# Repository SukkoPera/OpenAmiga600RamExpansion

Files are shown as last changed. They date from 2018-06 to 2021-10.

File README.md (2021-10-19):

# OpenAmiga600RamExpansion
OpenAmiga600RamExpansion is an Open Hardware 1 MB Chip RAM Expansion for the Commodore Amiga 600 Computer with optional Real Time Clock.

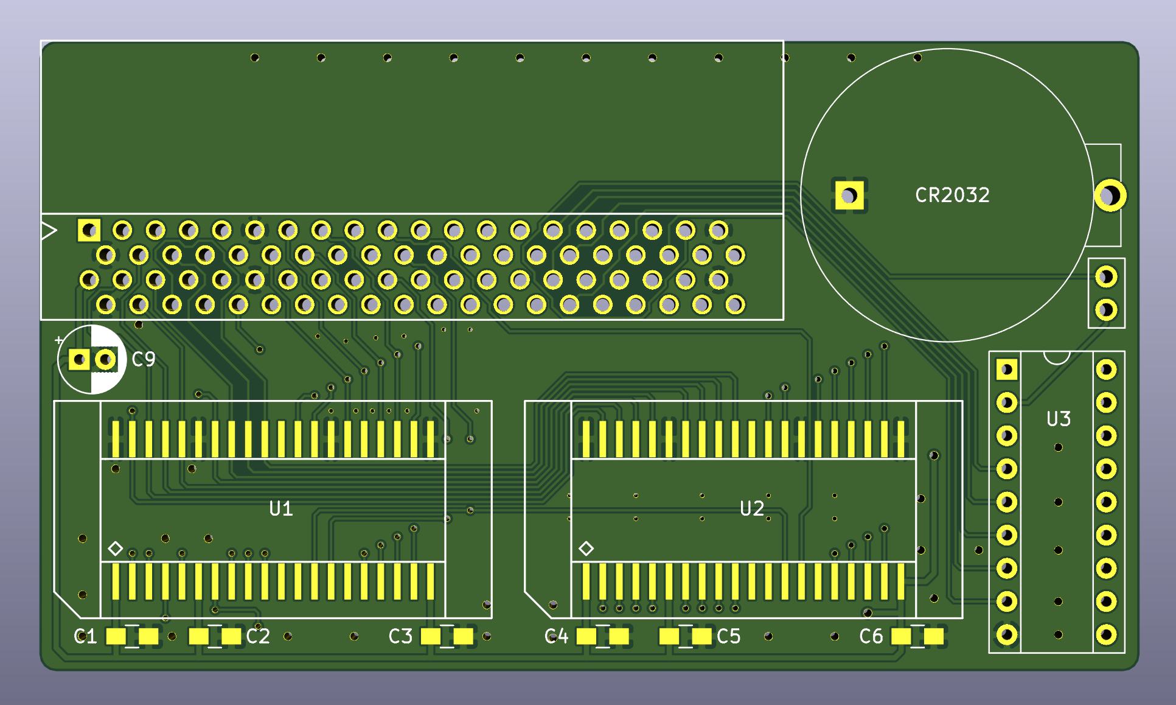
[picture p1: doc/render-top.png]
Board


### Summary
The Amiga 600 computer by Commodore originally came with 1 MB of Chip RAM. Like all "compact" Amiga models, it has a trapdoor in the bottom, through which a memory expansion can be installed, bringing the chip RAM to a maximum of 2 MB.

Back in the day, some expansions also came with a Real-Time Clock (RTC), which allowed the Amiga to keep track of the current date and time, which is most useful if you use AmigaDOS a lot. While this was mostly ordinary for Amiga 500 expansions, it was not so common on those for the Amiga 600, and even most expansions designed today do not bear an RTC circuit.

OpenAmiga600RamExpansion is an Open Hardware implementation of such an expansion, including the RTC.

Once you have maximized the Chip RAM in your A600, you might be interested in adding some **Fast** RAM as well: please check out [OpenAmiga600FastRamExpansion](https://github.com/SukkoPera/OpenAmiga600FastRamExpansion) in case.

### Components
#### Connector
The female connector for the male edge connector on the A600 PCB is probably the hardest part to get hold of. Many people use PCI connectors, which have the correct pitch but are longer and need to be trimmed. They are also hard to solder, most of the time. This project uses [a connector](https://coolcomponents.co.uk/products/edge-connector-for-bbc-micro-bit) that is normally used with the [micro:bit educational computer](http://microbit.org) instead. It was discovered by chance to be a perfect fit for the the A600, cheap and reliable.

#### Memory
The required RAM Type is 4 Mbit (256k×16) DRAM in the SOJ-40 package with up to 70-80 ns access time, e.g.:

|Model |Maker |Tested |Working |Data Sheet |Notes |
|---|---|:---:|:---:|:---:|---|
|AS4C256K16E0  |Alliance|Yes  |Yes | | Tested by [Marcovecchio](https://github.com/Marcovecchio). Used `-50JC` speed variant.  | |PDF (http://www.dexsilicium.com/Alliance_AS4C256K16E0.pdf) | |
|HM514260AJ8 |Hitachi |No  | | | |
|HM514260JP8 |Hitachi |No  | | | |
|HY514260BJC |Hyundai |Yes  |Yes | | Tested by [Marcovecchio](https://github.com/Marcovecchio). Used `-70` speed variant.  | 
|KM416C256BJ |Samsung |Yes  |Yes | | Tested by [tehKaiN](https://github.com/tehKaiN). Used `-4` speed variant. |
|M514260C |OKI |Yes  |Yes | | Tested by [tehKaiN](https://github.com/tehKaiN). Used `-60J` speed variant. |
|IC41C16257-35K|ICSI |Yes|Yes  |PDF (http://pdf.datasheetcatalog.com/datasheet2/f/0x3d8ida5x0jift9qq8jrfp8adpy.pdf) |Tested by go0se@AmiBay. _-S_ version should work, too. Do NOT use _LV_ versions. |
|T224162B |Tmtech  |Yes  |Yes |PDF (https://pdf1.alldatasheet.com/datasheet-pdf/view/29544/TMT/T224162B-35.html) | Tested by [Occupied](https://github.com/Occupied) Used `-35J` speed variant. | |
|µPD424260 |NEC |No  | | | |
|V53C16256HK50 |MOSEL VITELIC |Yes|Yes  |PDF (https://www.digchip.com/datasheets/parts/datasheet/308/V53C16256HK50-pdf.php) | |
|V53C16258HK30/35/50 |MOSEL VITELIC |Yes|Yes  |PDF (https://www.digchip.com/datasheets/parts/datasheet/308/V53C16258HK35-pdf.php) | |
|V53C16258SHK50|MOSEL VITELIC |Yes|Yes  |PDF (https://www.digchip.com/datasheets/parts/datasheet/308/V53C16258SHK50-pdf.php) | |

Most of these chips can be found on eBay or on AliExpress very cheaply (i.e.: 1-2€ each).

Normally it is not necessary to mount all the decoupling capacitors. I usually skip C2 and C4. All of them are 100nF in the 0805 package anyway. An additional 10uF electrolytic capacitor can be mounted at C9, if needed. Might be a good idea if using a *Vampire* board or a power-hungry machine.

RAM chips can either be soldered directly on the board or installed in sockets. While soldering the chips might not be trivial for the unexperienced, sockets for the SOJ-40 package are quite expensive and not really easier to solder either, so the choice is up to you.

#### RTC
The entire RTC circuit is optional. It has been designed for an Epson [RTC62421](http://pdf.datasheetcatalog.com/datasheets/90/339927_DS.pdf) or [RTC72421](http://pdf.datasheetcatalog.com/datasheet/epson/RTC-72423.pdf), which don't need an external crystal nor any calibration. Both can be bought very cheaply from China: they will most likely be second-hand "pulls", but usually they will work fine.

The other components have some degree of flexibility:
- C7: 100 nF 0805 capacitor
- C8: >= 2.2 μF >= 10 V 1206 tantalum capacitor
- R1, R2, R3: 10K 0805 resistor
- R4, R5: 220-470 0805 resistor
- D1: BAT721C or BAT54C diode
- Battery Holder: Some cheap eBay one, usually called *BS-7*
- Battery: CR2032 3V Non-Rechargeable Lithium (a new one will last years)

Note that if you plan to shelve your Amiga or not to use it for a while, **you are recommended to remove the RTC battery**. Failing to do so killed many A500+ computers and many A501 expansions in the past. The CR2032 battery used in this project is probably safer than the barrel batteries used in those devices, but still I would not leave one in an unused Amiga. You have been warned.

### Installation
After everything has been soldered, just open the trapdoor on your Amiga, install the expansion (the correct orientation is with the chips closer to the keyboard) and put the cover back on.

I recommend to run [Amiga Test Kit (formerly SysTest)](https://github.com/keirf/Amiga-Stuff) then. Use the Memory option (<kbd>F1</kbd>), it must show 2 MB of Chip RAM. Then start the Memory Test (<kbd>F1</kbd> again) and let it run for 50-100 rounds: if it doesn't find any errors, you are probably good to go.

Amiga Test Kit also has an option for reading and resetting the RTC (<kbd>F7</kbd> then <kbd>F3</kbd>), so try that as well. If you are using Amiga Test Kit or SysTest >= 1.2 you can also set the date and time with it, otherwise you will have to use other tools (Workbench is a good candidate).

### Issues
The board has been thoroughly tested and it works perfectly, but if you are trying to understand how it works, please be aware that [there are some oddities in the schematics](https://github.com/SukkoPera/OpenAmiga600RamExpansion/issues/7).

### License
The OpenAmiga600RamExpansion documentation, including the design itself, is copyright &copy; SukkoPera 2019.

OpenAmiga600RamExpansion is Open Hardware licensed under the [CERN OHL v. 1.2](http://ohwr.org/cernohl).

You may redistribute and modify this documentation under the terms of the CERN OHL v.1.2. This documentation is distributed *as is* and WITHOUT ANY EXPRESS OR IMPLIED WARRANTIES whatsoever with respect to its functionality, operability or use, including, without limitation, any implied warranties OF MERCHANTABILITY, SATISFACTORY QUALITY, FITNESS FOR A PARTICULAR PURPOSE or infringement. We expressly disclaim any liability whatsoever for any direct, indirect, consequential, incidental or special damages, including, without limitation, lost revenues, lost profits, losses resulting from business interruption or loss of data, regardless of the form of action or legal theory under which the liability may be asserted, even if advised of the possibility or likelihood of such damages.

A copy of the full license is included in file [LICENSE.pdf](LICENSE.pdf), please refer to it for applicable conditions. In order to properly deal with its terms, please see file [LICENSE_HOWTO.pdf](LICENSE_HOWTO.pdf).

The contact points for information about manufactured Products (see section 4.2) are listed in file [PRODUCT.md](PRODUCT.md).

Any modifications made by Licensees (see section 3.4.b) shall be recorded in file [CHANGES.md](CHANGES.md).

The Documentation Location of the original project is https://github.com/SukkoPera/OpenAmiga600RamExpansion/.

### Support the Project
Since the project is open you are free to get the PCBs made by your preferred manufacturer, however in case you want to support the development, you can order them from PCBWay through this link:

PCB from PCBWay (https://www.pcbway.com/project/shareproject/OpenAmiga600RamExpansion_V1.html)

You get my gratitude and cheap, professionally-made and good quality PCBs, I get some credit that will help with this and [other projects](https://www.pcbway.com/project/member/shareproject/?bmbid=41100). You won't even have to worry about the various PCB options, it's all pre-configured for you!

Also, if you still have to register to that site, [you can use this link](https://www.pcbway.com/setinvite.aspx?inviteid=41100) to get some bonus initial credit (and yield me some more).

Again, if you want to use another manufacturer, feel free to, don't feel obligated :). But then, you can buy me a coffee if you want:

<a href='https://ko-fi.com/L3L0U18L' target='_blank'>Buy Me a Coffee at ko-fi.com</a>

### Get Help
If you need help or have questions, you can join [the official Telegram group](https://t.me/joinchat/HUHdWBC9J9JnYIrvTYfZmg).

### Thanks
- Thanks to the guys at the Italian Amiga Page forum, in particular:
  - fpmpaolo for suggesting the idea of making such a board
  - cpiace64 for providing me with a board to use as a template
  - majinga for helping with the testing
- The RTC circuit was copied shamelessly from the [Amiga 500 Expansion designed by PeteAU](http://eab.abime.net/showthread.php?t=85395) (which in turn probably copied it from Commodore).
- Footprint for [micro:bit edge connector](https://coolcomponents.co.uk/products/edge-connector-for-bbc-micro-bit) derived from work by [Anthony Kirby](https://github.com/anthonykirby/kicad_microbit_connector).
- Footprint for BS-7 Battery Holder taken from the [digikey-kicad-library](https://github.com/digikey/digikey-kicad-library).

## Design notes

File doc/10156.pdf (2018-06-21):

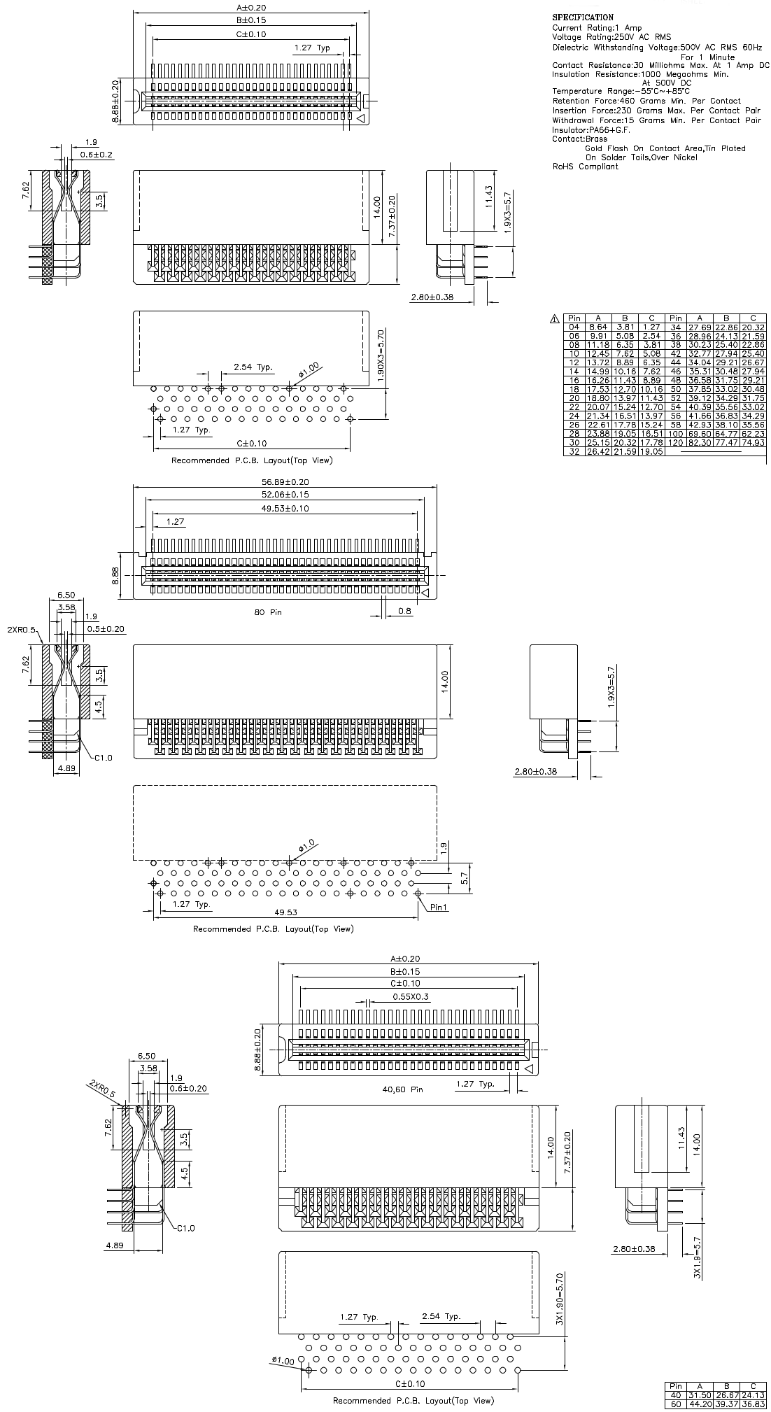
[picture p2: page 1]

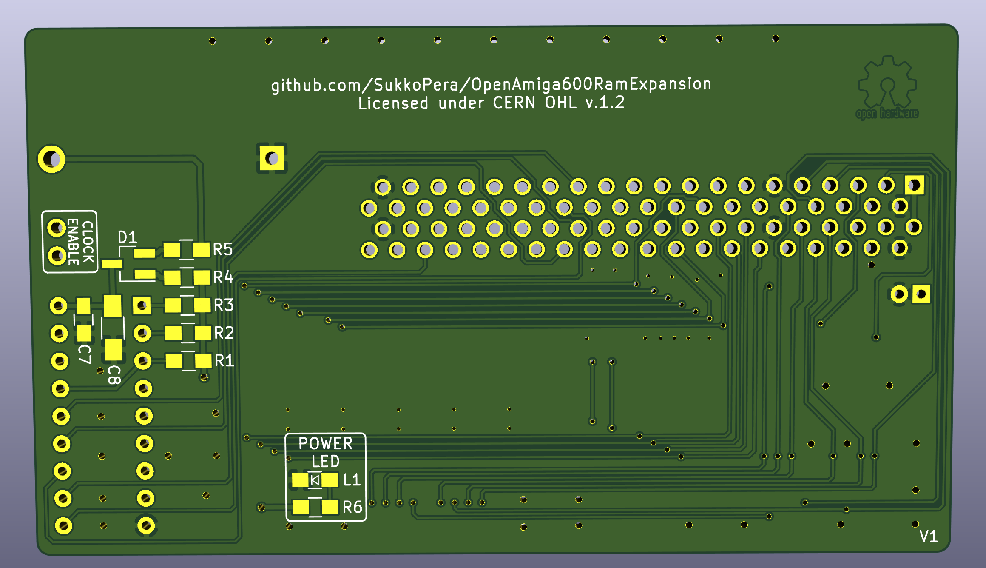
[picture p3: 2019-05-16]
doc/render-bottom.png

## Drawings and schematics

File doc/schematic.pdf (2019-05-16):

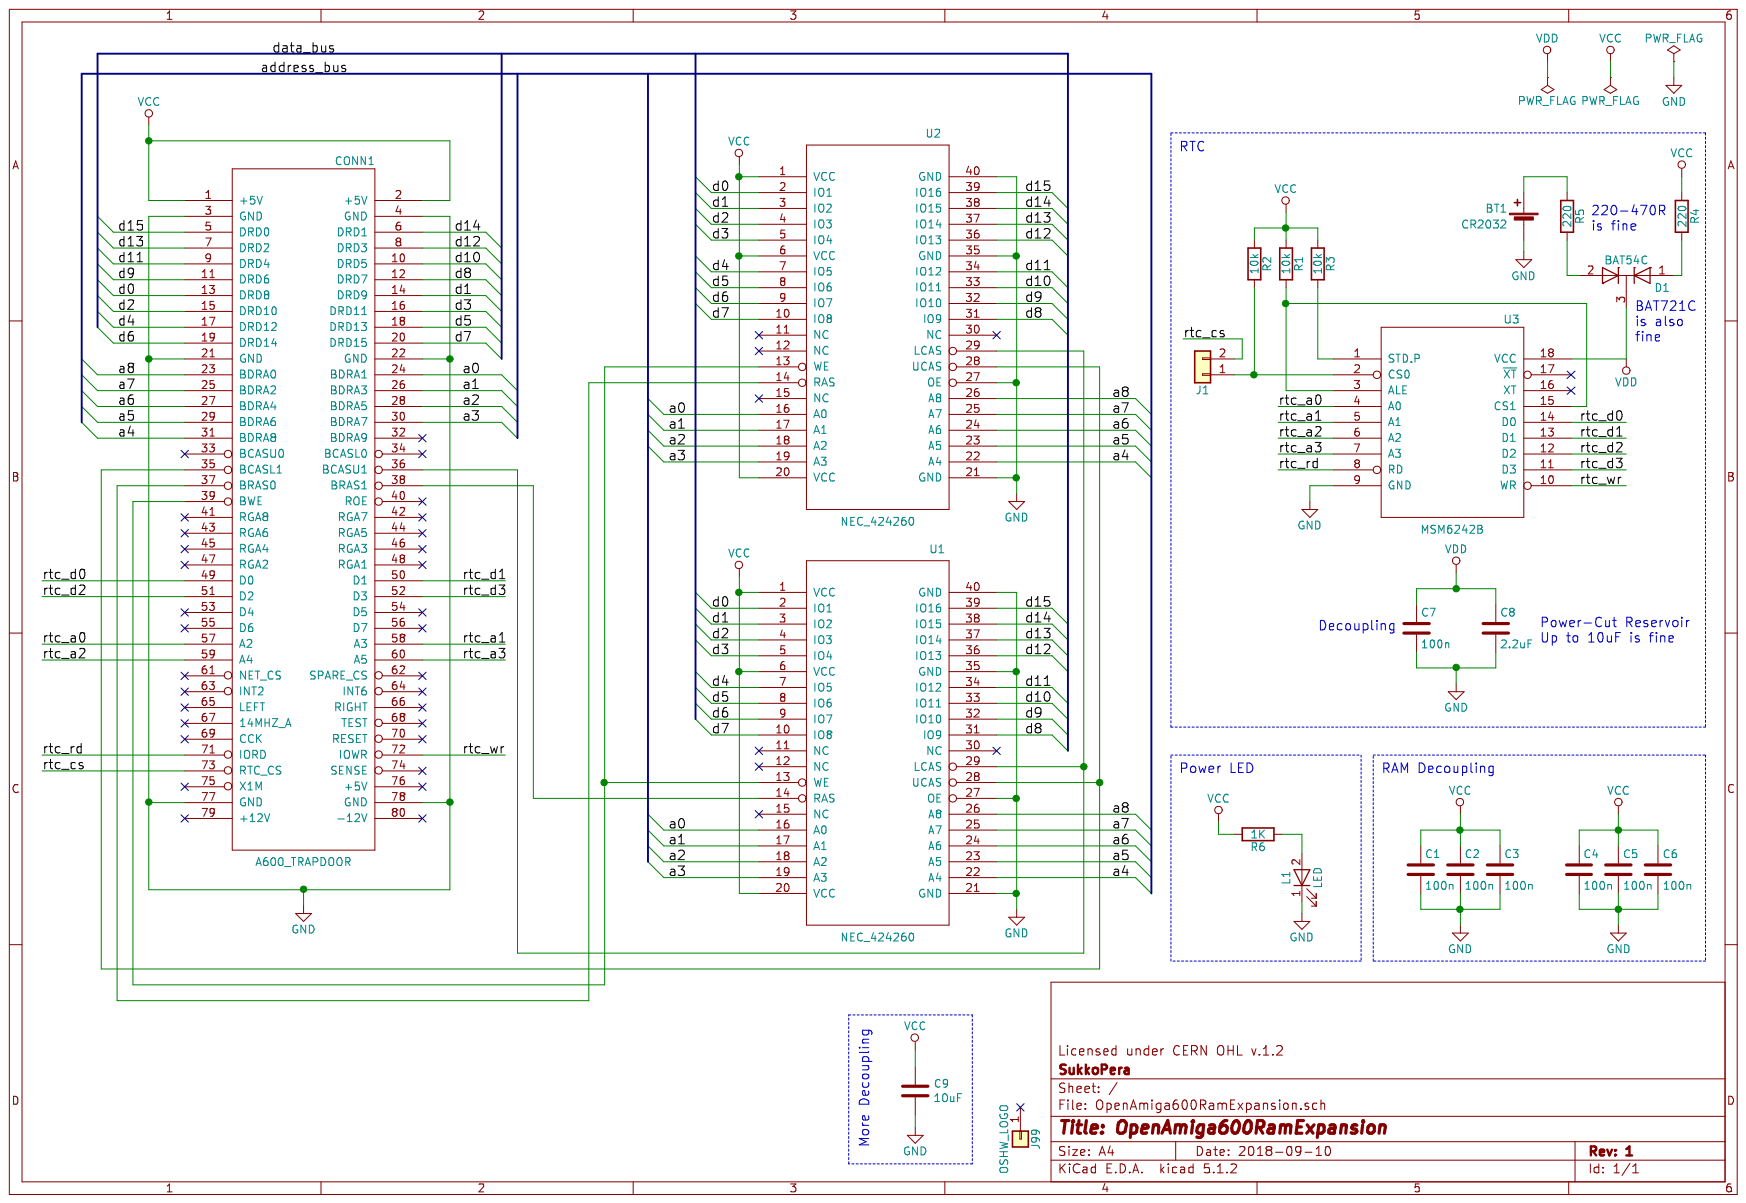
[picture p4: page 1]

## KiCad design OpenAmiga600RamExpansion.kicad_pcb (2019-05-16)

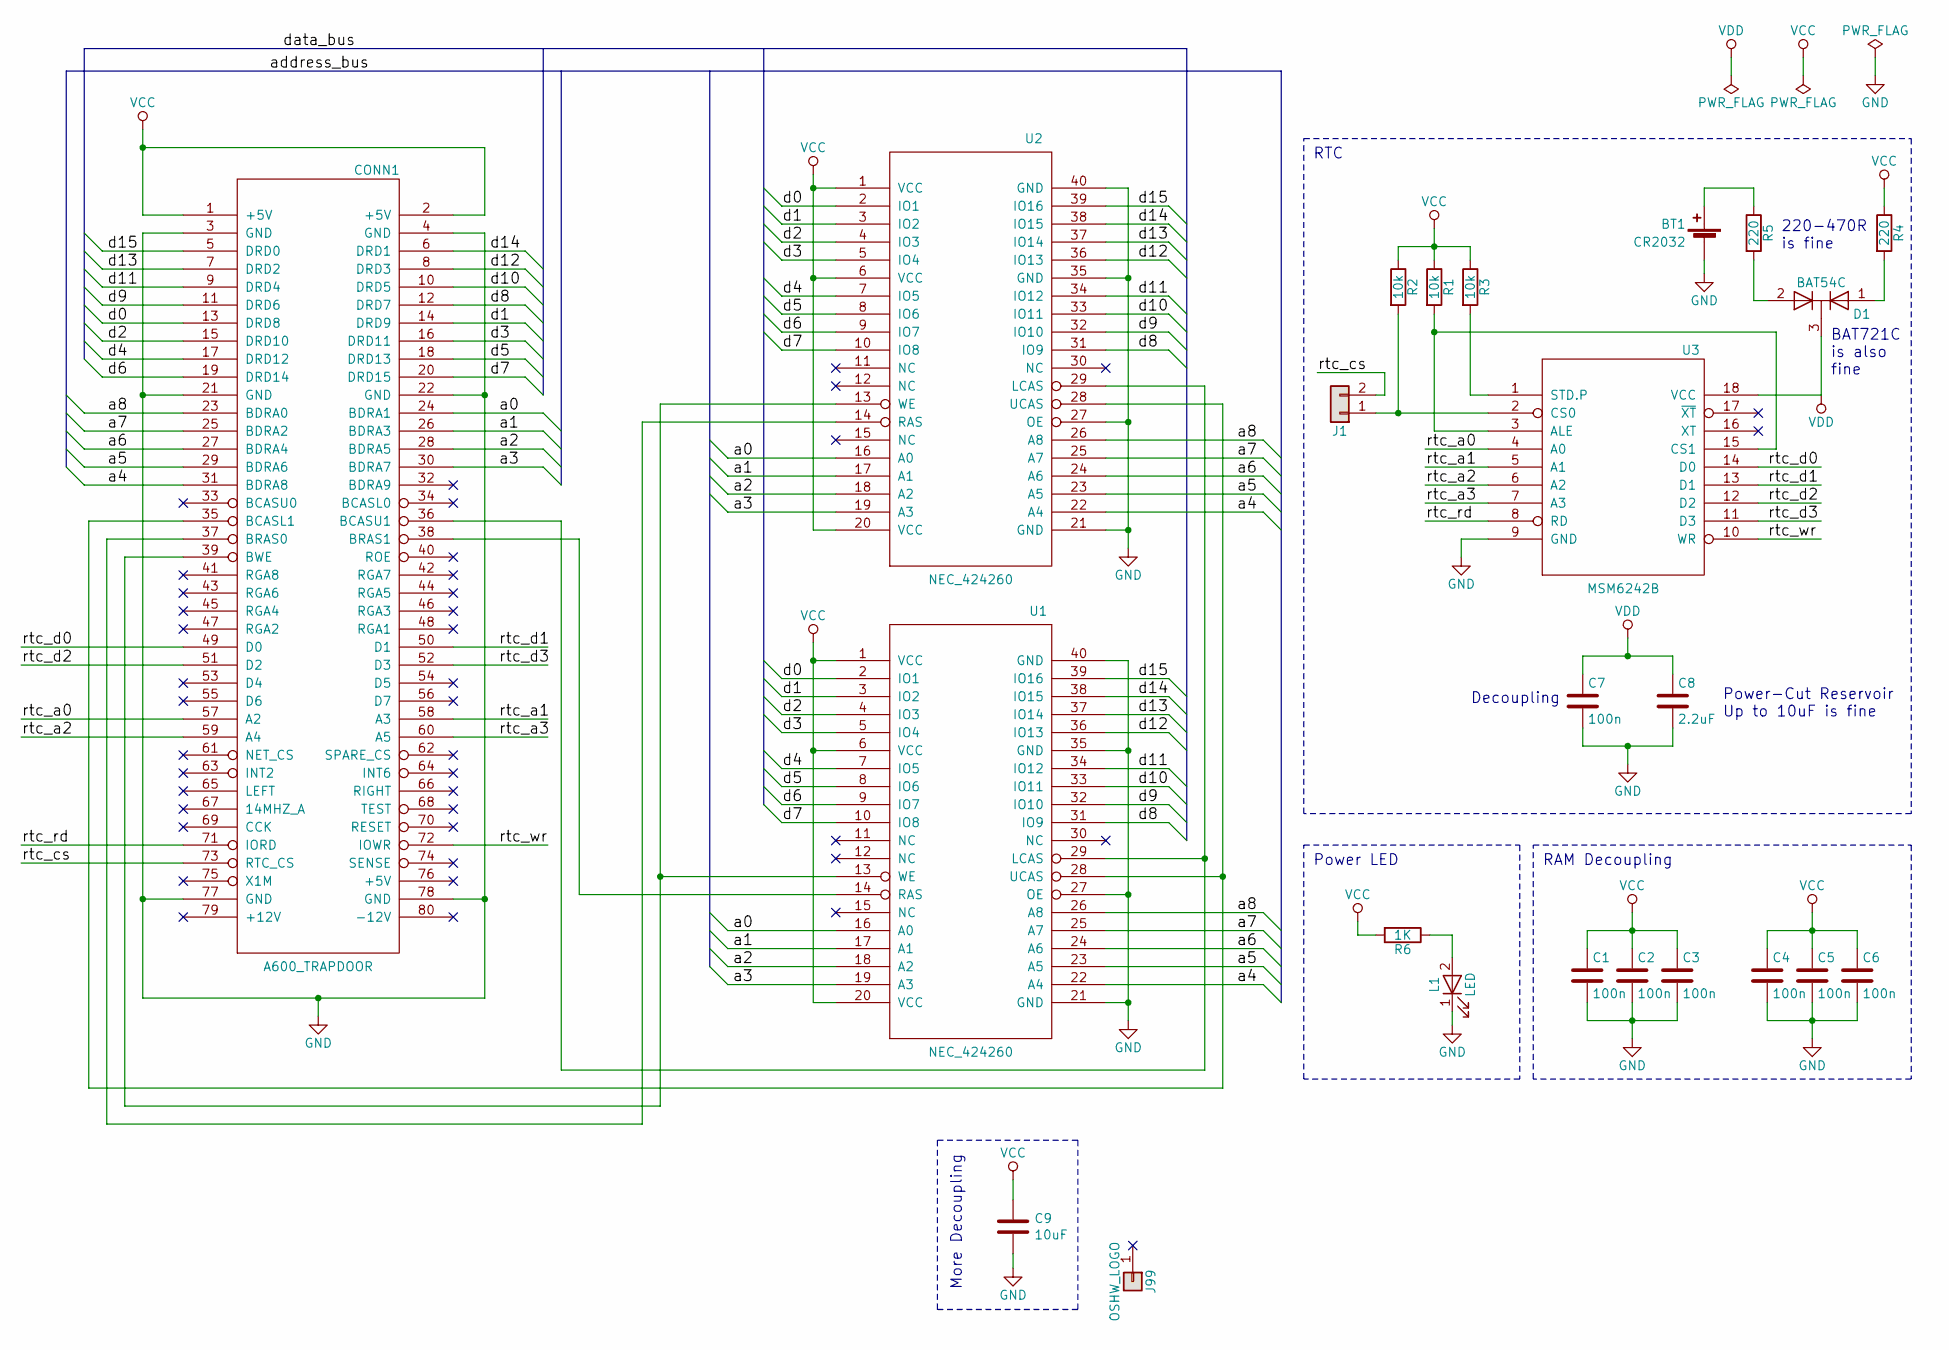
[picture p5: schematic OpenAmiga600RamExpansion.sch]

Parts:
BT1: CR2032; Battery_Holder_Coin_2032_BS-7
C1, C2, C3, C4, C5, C6, C7: 100n; C_0805_HandSoldering
C8: 2.2uF; C_1206_HandSoldering
C9: 10uF; CP_Radial_D5.0mm_P2.00mm
CONN1: A600_TRAPDOOR; 4UCON_10156_90deg
D1: BAT54C; SOT-23_Handsoldering
J1: Conn_01x02; Pin_Header_Straight_1x02-ModSilkS
J99: OSHW_LOGO; Logo_copper_OSHW_6x6mm
L1: LED; LED_0805_HandSoldering_ModSilkS
R1, R2, R3: 10k; R_0805_HandSoldering
R4, R5: 220; R_0805_HandSoldering
R6: 1K; R_0805_HandSoldering
U1, U2: NEC_424260; SOJ-40-Socket-LongPads
U3: MSM6242B; DIP-18_W7.62mm_Socket

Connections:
/a0: CONN1.24 (BDRA1), U1.16 (A0), U2.16 (A0)
/a1: CONN1.26 (BDRA3), U1.17 (A1), U2.17 (A1)
/a2: CONN1.28 (BDRA5), U1.18 (A2), U2.18 (A2)
/a3: CONN1.30 (BDRA7), U1.19 (A3), U2.19 (A3)
/a4: CONN1.31 (BDRA8), U1.22 (A4), U2.22 (A4)
/a5: CONN1.29 (BDRA6), U1.23 (A5), U2.23 (A5)
/a6: CONN1.27 (BDRA4), U1.24 (A6), U2.24 (A6)
/a7: CONN1.25 (BDRA2), U1.25 (A7), U2.25 (A7)
/a8: CONN1.23 (BDRA0), U1.26 (A8), U2.26 (A8)
/d0: CONN1.13 (DRD8), U1.2 (IO1), U2.2 (IO1)
/d1: CONN1.14 (DRD9), U1.3 (IO2), U2.3 (IO2)
/d2: CONN1.15 (DRD10), U1.4 (IO3), U2.4 (IO3)
/d3: CONN1.16 (DRD11), U1.5 (IO4), U2.5 (IO4)
/d4: CONN1.17 (DRD12), U1.7 (IO5), U2.7 (IO5)
/d5: CONN1.18 (DRD13), U1.8 (IO6), U2.8 (IO6)
/d6: CONN1.19 (DRD14), U1.9 (IO7), U2.9 (IO7)
/d7: CONN1.20 (DRD15), U1.10 (IO8), U2.10 (IO8)
/d8: CONN1.12 (DRD7), U1.31 (IO9), U2.31 (IO9)
/d9: CONN1.11 (DRD6), U1.32 (IO10), U2.32 (IO10)
/d10: CONN1.10 (DRD5), U1.33 (IO11), U2.33 (IO11)
/d11: CONN1.9 (DRD4), U1.34 (IO12), U2.34 (IO12)
/d12: CONN1.8 (DRD3), U1.36 (IO13), U2.36 (IO13)
/d13: CONN1.7 (DRD2), U1.37 (IO14), U2.37 (IO14)
/d14: CONN1.6 (DRD1), U1.38 (IO15), U2.38 (IO15)
/d15: CONN1.5 (DRD0), U1.39 (IO16), U2.39 (IO16)
/rtc_a0: CONN1.57 (A2), U3.4 (A0)
/rtc_a1: CONN1.58 (A3), U3.5 (A1)
/rtc_a2: CONN1.59 (A4), U3.6 (A2)
/rtc_a3: CONN1.60 (A5), U3.7 (A3)
/rtc_cs: CONN1.73 (RTC_CS), J1.2
/rtc_d0: CONN1.49 (D0), U3.14 (D0)
/rtc_d1: CONN1.50 (D1), U3.13 (D1)
/rtc_d2: CONN1.51 (D2), U3.12 (D2)
/rtc_d3: CONN1.52 (D3), U3.11 (D3)
/rtc_rd: CONN1.71 (IORD), U3.8 (RD)
/rtc_wr: CONN1.72 (IOWR), U3.10 (WR)
GND: BT1.2 (-), C1.2, C2.2, C3.2, C4.2, C5.2, C6.2, C7.2, C8.2, C9.2, CONN1.3 (GND), CONN1.4 (GND), CONN1.21 (GND), CONN1.22 (GND), CONN1.77 (GND), CONN1.78 (GND), L1.1 (K), U1.21 (GND), U1.27 (OE), U1.35 (GND), U1.40 (GND), U2.21 (GND), U2.27 (OE), U2.35 (GND), U2.40 (GND), U3.9 (GND)
unnamed: BT1.1 (+), R5.1
unnamed: CONN1.35 (BCASL1), U1.28 (UCAS), U2.28 (UCAS)
unnamed: CONN1.36 (BCASU1), U1.29 (LCAS), U2.29 (LCAS)
unnamed: CONN1.37 (BRAS0), U2.14 (RAS)
unnamed: CONN1.38 (BRAS1), U1.14 (RAS)
unnamed: CONN1.39 (BWE), U1.13 (WE), U2.13 (WE)
unnamed: D1.1 (A), R4.2
unnamed: D1.2 (A), R5.2
unnamed: J1.1, R2.2, U3.2 (CS0)
unnamed: L1.2 (A), R6.1
unnamed: R1.2, U3.3 (ALE), U3.15 (CS1)
unnamed: R3.2, U3.1 (STD.P)
VCC: C1.1, C2.1, C3.1, C4.1, C5.1, C6.1, C9.1, CONN1.1 (+5V), CONN1.2 (+5V), R1.1, R2.1, R3.1, R4.1, R6.2, U1.1 (VCC), U1.6 (VCC), U1.20 (VCC), U2.1 (VCC), U2.6 (VCC), U2.20 (VCC)
VDD: C7.1, C8.1, D1.3 (K), U3.18 (VCC)

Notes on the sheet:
RTC
Decoupling
RAM Decoupling
Power-Cut Reservoir Up to 10uF is fine
220-470R is fine
BAT721C is also fine
Power LED
More Decoupling

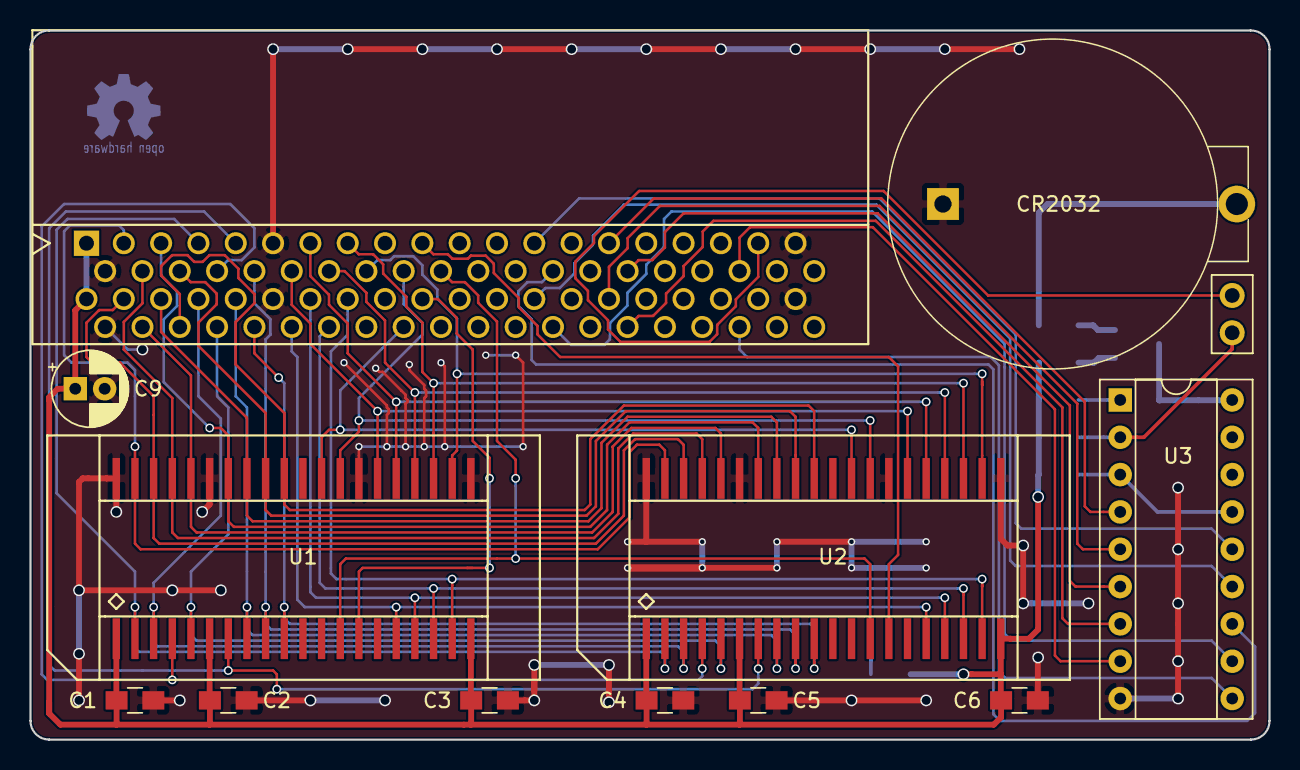
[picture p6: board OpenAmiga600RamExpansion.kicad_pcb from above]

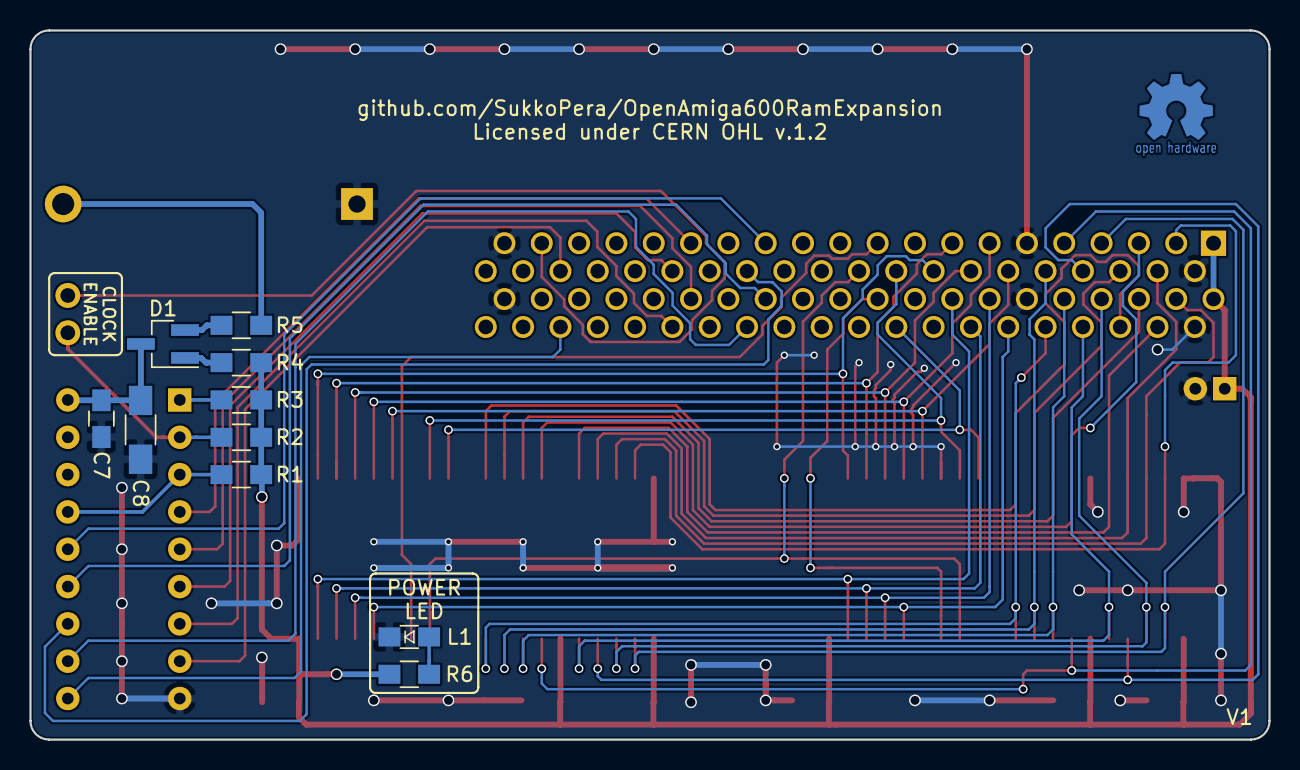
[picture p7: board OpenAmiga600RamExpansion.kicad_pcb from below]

Board: 2 copper layers, 84.3 x 48.3 mm, 24 parts (11 on the bottom side), 51 nets.

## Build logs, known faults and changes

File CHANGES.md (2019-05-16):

## CHANGES

Any modifications to the OpenAmiga600RamExpansion design and documentation made by any Licensee MUST be noted in this file, as per *section 3.4.b* of the [license](LICENSE.pdf).

### (Date) - (Author)
(Description)

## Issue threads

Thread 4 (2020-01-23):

Edge connector

patzik, 2020-01-23:
Seems there is another version of the edge connector available.
I think it's easier to get, and cheaper, so maybe you could make another branch for this?

https://www.aliexpress.com/item/4000330557659.html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,scm-url:1007.13338.146400.0,pvid:c47b52e1-4d48-46e7-bc51-7ae1a9f07dd6

SukkoPera, 2020-01-23:
This sounds interesting, but it would require rerouting part of the PCB and I really don't have time for that now. Plus I'm not sure it's worth saving a few Euros for a connector of unknown quality.

Anyway I'll leave this open, I'll order a couple of those and look at it when I have time. Or if someone wants to help... :)

patzik, 2020-01-23:
Totally understand, just wanted to give you a heads-up about this. I can only work with eagle, tried kicad a month ago, but I don’t understand a thing of it 😁

SukkoPera, 2020-01-24:
For me it's exactly the opposite: tried Eagle a couple of times but never managed to do anything productive.

Anyway thanks for the info, sooner or later it will be useful ;).

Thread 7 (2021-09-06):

Data Lines switched

Avinitlarge, 2021-09-06:
HI Mr Sukkopera
Ive noticed all of the Data lines are switched and don't follow the Amiga Schematic, D0-15 and UCAS/LCAS.

SukkoPera, 2021-09-27:
You are definitely right, data lines and address lines are numbered incorrectly. I probably followed some random connector pinout I found online, but can't remember which one. For some reason I also crossed UCAS and LCAS, which luckily allows the expansion to work.

Thanks for the heads up, I will add a pointer to this issue in the docs.

SukkoPera, 2021-09-27:
This is the correct pinout:
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

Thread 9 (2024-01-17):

Soldering SOJ Hack

122christo, 2024-01-17:
Hello!
Soldering SOJ-Chips is not easy. So I made a hack:
I soldered some Female PCB connector, like this one:
https://www.atd-shop.com/qx22B3-en/female-header-rm-127-mm-smt-single-row
on the PCB, bended the pins of the RAM-Chip into shape and put the pins in the
connector. Its like a socket, but much easier to solder. It works without Error.

SukkoPera, 2024-01-18:
What you did is not very clear to me, can you please post a picture?

Anyway, even the "real" SOJ sockets are quite unreliable, they often fail after some time. I strongy recommend to solder the chips, it's not that hard if you have a good iron and good wire :).

SukkoPera, 2024-01-18:
That's a neat hack but it really doesn't look "solid" to me. I'm pretty sure it will cause problems in the future and it actually greatly increases the soldering time and effort.

You might be using solder wire that is too thick. 0.5 mm makes this kind of jobs much easier.

Anyway thanks for sharing!

Closed 2024-01-18.

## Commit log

2018-06-21 Schematics should be final. PCB will come, one day...
2018-06-24 Fix error in RTC power circuit
    [OpenAmiga600RamExpansion.kicad_pcb, OpenAmiga600RamExpansion.sch]
2018-06-26 Reposition some RTC components
    [OpenAmiga600RamExpansion.kicad_pcb, OpenAmiga600RamExpansion.sch]
2018-06-26 Minor silkscreen fixes
    [OpenAmiga600RamExpansion.kicad_pcb, OpenAmiga600RamExpansion.sch]
2018-06-28 The sweetest perfection ;)
    [OpenAmiga600RamExpansion.kicad_pcb, OpenAmiga600RamExpansion.sch]
2018-09-10 Add RAM compatibility list and RTC BOM
2018-09-10 Use HandSoldering version of SOT-23 footprint
    [OpenAmiga600RamExpansion.kicad_pcb, OpenAmiga600RamExpansion.sch]
2018-09-10 Switch to KiCad 5
    [OpenAmiga600RamExpansion.kicad_pcb, OpenAmiga600RamExpansion.sch]
2018-09-10 Add (optional) decoupling electrolytic cap, just in case
    [OpenAmiga600RamExpansion.kicad_pcb, OpenAmiga600RamExpansion.sch]
2018-09-10 Update schematic
2019-05-08 Samsung KM416C256BJ and OKI M514260C compatibility
    I'm kinda nuts so I've soldered my expansion two different chips and they work! Tested under Advanced Amiga Analyzer's memtest 3 times.
2019-05-16 Add license
    [OpenAmiga600RamExpansion.kicad_pcb, OpenAmiga600RamExpansion.sch]
2019-05-16 Add license on schematics PDF
2026-02-13 Update README to remove outdated content
    Removed old Ko-fi button and help section from README.

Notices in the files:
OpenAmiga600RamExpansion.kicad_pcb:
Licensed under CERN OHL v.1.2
